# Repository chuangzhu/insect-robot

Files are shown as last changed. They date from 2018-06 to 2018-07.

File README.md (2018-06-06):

__中文 | [English](./README.en.md)__
# Insect Robot
用你的手机控制一只昆虫。  
>This project is greatly inspired by [Backyardbrains/Roboroach](https://github.com/backyardbrains/roboroach).  

insrobotop

insrobopack

## 开始
```Shell
git clone --recursive https://github.com/genelocated/insect-robot.git
```
#### 硬件
用 Eagle 7.7.0 打开 `hard/insect-robot.brd` 文件，选择 `文件 > CAM 处理器...` 。  
`文件 > 打开 > 作业...` , 打开 `gerb274x.cam` , 处理作业。  
打开作业 `excellon.cam` , 处理作业。  
将生成的 gerber 文件发给 pcb 打样厂。

#### 被控端固件

由于主控芯片采用的是 AVR，所以兼容 Arduino。可以使用 Arduino IDE 编程，具体请见 [arduino](./arduino/) 目录。

另一种方法：用 atmel studio 打开 `avr/controlled/insectRobot.atsln` , 运行 `build > build solution` 。  
生成的 hex 文件为 `Debug/controlled.hex` , 用 avrdude 或 progisp 烧录。需要用到 AVR asp。  
你还需要买一块 [FPC 6p 转接板](https://s.taobao.com/search?q=fpc+转接板+直插)。

#### 手机端
用微信扫描以下二维码打开小程序：  
QRcode

## 许可协议
本项目为开源硬件项目。

  
该项目本身采用[知识共享署名-相同方式共享 4.0 国际许可协议](https://creativecommons.org/licenses/by-sa/4.0/deed.zh)进行许可。  
小程序使用 MIT 协议进行许可。

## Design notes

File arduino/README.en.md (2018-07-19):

__English | [中文](./README.md)__

# Program using Arduino IDE

## Preparation

Locate at your Arduino config folder, it should one of the listed below:

```
\Arduino15\ (Windows, Arduino IDE 1.6.6 and newer)
\Arduino\ (Windows, Arduino IDE 1.0.6 and older)
\Documents\ArduinoData\ (Windows app version)
~/Library/Arduino15/ (Max OS X, Arduino IDE 1.6.0 and newer)
~/Library/Arduino/ (Max OS X, Arduino IDE 1.0.6 and older)
~/.arduino15/ (Linux, Arduino IDE 1.6.0 and newer)
~/.arduino/ (Linux, Arduino IDE 1.0.6 and older)
<Arduino IDE installation folder>/portable/ (when used in portable mode)
```

Open `packages/arduino/hardware/avr/1.6.21/boards.txt`, insert this content at the beginning of the file:

```makefile
insrobo.name=Insect Robot

insrobo.upload.tool=avrdude
insrobo.upload.protocol=arduino

insrobo.bootloader.tool=avrdude
insrobo.bootloader.unlock_bits=0x3F
insrobo.bootloader.lock_bits=0x0F

insrobo.build.board=AVR_PRO
insrobo.build.core=arduino
insrobo.build.variant=eightanaloginputs

insrobo.upload.maximum_size=30720
insrobo.upload.maximum_data_size=2048
insrobo.upload.speed=57600

insrobo.bootloader.low_fuses=0xE2
insrobo.bootloader.high_fuses=0xD9
insrobo.bootloader.extended_fuses=0xFF
insrobo.bootloader.file=atmega/ATmegaBOOT_168_atmega328.hex

insrobo.build.mcu=atmega328p
insrobo.build.f_cpu=8000000L
```

Besides, you may need a [USBtinyISP](https://www.amazon.com/s/field-keywords=USBtinyISP) to program.

## Let's start

Connect the board, the programmer and your computer in the way as is shown in the photo:

![connectprogrammer]()

Open Arduino IDE, select "Insect Robot" for board and "USBtinyISP" for programmer in "Tools" menu.

arduinotools

Then press "Upload Using Programmer" in the "Sketch" menu.

uploadwithprogrammer

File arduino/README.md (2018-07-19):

__中文 | [English](./README.en.md)__

# 使用 Arduino IDE 编程

## 准备工作

打开你的 Arduino 配置文件夹，它应该是以下其一：

```
\Arduino15\ (Windows, Arduino IDE 1.6.6 and newer)
\Arduino\ (Windows, Arduino IDE 1.0.6 and older)
\Documents\ArduinoData\ (Windows app version)
~/Library/Arduino15/ (Max OS X, Arduino IDE 1.6.0 and newer)
~/Library/Arduino/ (Max OS X, Arduino IDE 1.0.6 and older)
~/.arduino15/ (Linux, Arduino IDE 1.6.0 and newer)
~/.arduino/ (Linux, Arduino IDE 1.0.6 and older)
<Arduino IDE installation folder>/portable/ (when used in portable mode)
```

打开该目录下的 `packages\arduino\hardware\avr\1.6.21\boards.txt`，在文件开头粘贴以下内容：

```makefile
insrobo.name=Insect Robot

insrobo.upload.tool=avrdude
insrobo.upload.protocol=arduino

insrobo.bootloader.tool=avrdude
insrobo.bootloader.unlock_bits=0x3F
insrobo.bootloader.lock_bits=0x0F

insrobo.build.board=AVR_PRO
insrobo.build.core=arduino
insrobo.build.variant=eightanaloginputs

insrobo.upload.maximum_size=30720
insrobo.upload.maximum_data_size=2048
insrobo.upload.speed=57600

insrobo.bootloader.low_fuses=0xE2
insrobo.bootloader.high_fuses=0xD9
insrobo.bootloader.extended_fuses=0xFF
insrobo.bootloader.file=atmega/ATmegaBOOT_168_atmega328.hex

insrobo.build.mcu=atmega328p
insrobo.build.f_cpu=8000000L
```

此外，你还需要购买一个 [USBtinyISP](https://s.taobao.com/search?q=USBtinyISP)。

## 开始编程

如图所示连接电路板、编程器和电脑：

![connectprogrammer]()

打开 Arduino IDE，在工具中将开发板设置为 Insect Robot、编程器设置为 USBtinyISP。

arduinotools

点击项目菜单中的”使用编程器上传“即可。

uploadwithprogrammer

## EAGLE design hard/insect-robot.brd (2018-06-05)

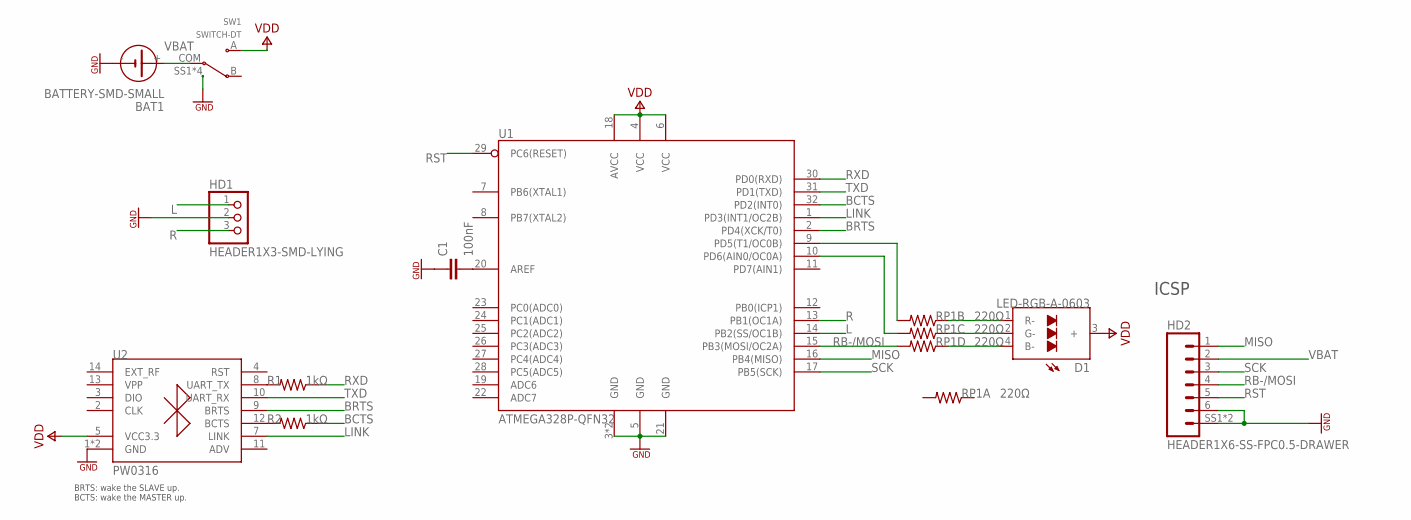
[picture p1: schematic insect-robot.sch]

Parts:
BAT1: BATTERY-SMD-SMALL; BAT-SMD-SMALL
C1: 100nF; SMD0603
D1: LED-RGB-A-0603; LED-0603X2
HD1: HEADER1X3-SMD-LYING; SMD-1X3-LYING
HD2: HEADER1X6-SS-FPC0.5-DRAWER; FPC0.5-6-DRAWER
R1, R2: 1kΩ; SMD0603
RP1: 220Ω; RP0603
SW1: SWITCH-DT; SWITCH-SMD-6.7X2.7
U1: ATMEGA328P-QFN32; QFN32
U2: PW0316

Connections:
AREF: C1.2, U1.20 (AREF)
B-: D1.4 (B-), RP1.7 (1)
BCTS: R2.1, U1.32 (PD2(INT0))
BRTS: U1.2 (PD4(XCK/T0)), U2.9 (BRTS)
G-: D1.2 (G-), RP1.5 (1)
GND: BAT1.-, C1.1, HD1.2, HD2.6, HD2.SS1 (7), HD2.SS2 (7), SW1.SS1 (SS), SW1.SS2 (SS), SW1.SS3 (SS), SW1.SS4 (SS), U1.3 (GND), U1.5 (GND), U1.21 (GND), U1.EP (GND), U2.1 (GND), U2.6 (GND)
L: HD1.1, U1.14 (PB2(SS/OC1B))
LINK: U1.1 (PD3(INT1/OC2B)), U2.7 (LINK)
MISO: HD2.1, U1.16 (PB4(MISO))
R: HD1.3, U1.13 (PB1(OC1A))
R-: D1.1 (R-), RP1.3 (1)
R-BCTS: R2.2, U2.12 (BCTS)
R-TX: R1.2, U2.8 (UART_TX)
RB-/MOSI: HD2.4, RP1.8 (2), U1.15 (PB3(MOSI/OC2A))
RG-: RP1.6 (2), U1.10 (PD6(AIN0/OC0A))
RR-: RP1.4 (2), U1.9 (PD5(T1/OC0B))
RST: HD2.5, U1.29 (PC6(RESET))
RXD: R1.1, U1.30 (PD0(RXD))
SCK: HD2.3, U1.17 (PB5(SCK))
TXD: U1.31 (PD1(TXD)), U2.10 (UART_RX)
VBAT: BAT1.+, HD2.2, SW1.COM
VDD: D1.3 (+), SW1.A, U1.4 (VCC), U1.6 (VCC), U1.18 (AVCC), U2.5 (VCC3.3)

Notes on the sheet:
ICSP
BRTS: wake the SLAVE up. BCTS: wake the MASTER up.

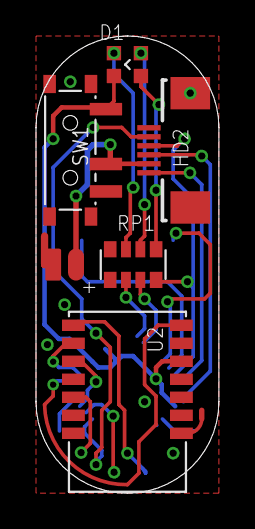
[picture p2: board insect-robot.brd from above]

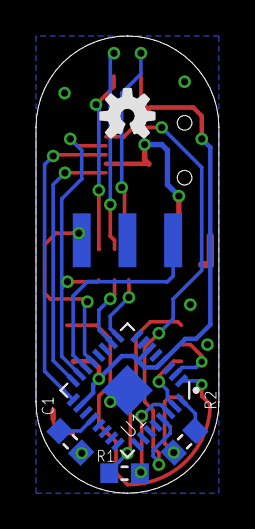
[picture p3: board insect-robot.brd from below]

Board: 2 copper layers, 10.2 x 25.4 mm, 12 parts (6 on the bottom side), 22 nets.

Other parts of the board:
OSHW: ICON-OSHW

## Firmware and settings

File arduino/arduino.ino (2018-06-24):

/* Don't save this file as "UTF-8 with BOM" */

// color ranges from 0x00 to 0xFF,
// we use an array of char to store r, g, b
// in this case we can send it via BLE boardcast
char ledColor[3];

void randColor() {
  for (int i = 0; i<3; i++) {
    // use the values read from unconnected analog pins as random seed
    randomSeed(analogRead(3) + analogRead(6));
    ledColor[i] = random(256);
  }
}

// LED pins
const int RED = 5;
const int GREEN = 6;
const int BLUE = 11;
// electrode pins
const int LEFT = 10;
const int RIGHT = 9;

void setup() {
  pinMode(RED, OUTPUT);
  pinMode(GREEN, OUTPUT);
  pinMode(BLUE, OUTPUT);
  // a pin is in Hi-Z state when it is INPUT and LOW.
  // we only make these pins OUTPUT when we need to make them HIGH.
  // this measure prevented the possibility of
  // letting the current flows from one antenna to another.
  pinMode(LEFT, INPUT);
  pinMode(RIGHT, INPUT);
  randColor(); // get a random color
  // show this random color on the LED
  analogWrite(RED, 255 - ledColor[0]);
  analogWrite(GREEN, 255 - ledColor[1]);
  analogWrite(BLUE, 255 - ledColor[2]);
  Serial.begin(9600);
  delay(128);
  // rename the bluetooth low energy (BLE) module to '$sect'
  Serial.println("TTM:REN-$sect");
  // leave time for the module to deal with the task
  delay(128);
  // share the random color via BLE boardcast 
  Serial.print("TTM:ADD-");
  Serial.print(ledColor);
  delay(255);
}



// parameters for the impulse wave
const int impulsePeriod = 30; // *10us
const int impulseDuty = 20; // *10us
const int impulseTimeout = 1000; // *10us

boolean impulse = false;
int impulsePin;
int loopStep = 0;
int impulseTimes = 0;

//   impulsePeriod
//  |<----------->|
//   __________    __________      HIGH
//             |  |          |
//             |__|          |__   LOW
//
//  |<-------->|             |<>|
//   impulseDuty        (impulsePriod - impulseDuty)
//
//           |   zoom out
//           V
//        _   _   _   _   _   _   _
//  ------ |_| |_| |_| |_| |_| |_| |_------
//       |<------------------------->|
//              impulseTimeout

void loop() {
  if (impulse) {
    if (loopStep == impulseDuty) {
      digitalWrite(impulsePin, LOW);
    } else if (loopStep == impulsePeriod) {
      loopStep = 0;
      digitalWrite(impulsePin, HIGH); 
    }
    loopStep ++;
    if (impulseTimes == impulseTimeout) {
      impulseTimes = 0;
      pinMode(impulsePin, INPUT);
      digitalWrite(impulsePin, LOW);
      impulse = false;
    }
    impulseTimes ++;
    delayMicroseconds(10);
  }
}



String inString = "";

void serialEvent() {
  while (Serial.available()) {
    char inChar = Serial.read();
    inString += inChar; // append to the string
    if (inString == "EL:LLL") {
      inString = "";
      impulsePin = LEFT;
      pinMode(impulsePin, OUTPUT);
      impulse = true; // start impulse wave
    } else if (inString == "EL:RRR") {
      inString = "";
      impulsePin = RIGHT;
      pinMode(impulsePin, OUTPUT);
      impulse = true;
    }
  }
}

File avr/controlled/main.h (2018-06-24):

/*
 * main.h
 *
 * Created: 2018/4/28 22:28:03
 *  Author: geneLocated
 */ 


#ifndef MAIN_H_
#define MAIN_H_

#include <avr/io.h>
#include <avr/interrupt.h>
#include <util/delay.h>
#include <stdlib.h>
#include <string.h>
#include "../lib/USART/HAL_USART.h"
#include "../lib/ADC/HAL_ADC.h"

//Pins definitions.
#define RXD		PORTD0
#define TXD		PORTD1
#define BCTS	PORTD2
#define LINK	PORTD3
#define BRTS	PORTD4

#define eleLeft		PORTB2
#define eleRight	PORTB1

//This commit corrected LED to PWM pins,
#define ledR PORTD5	//OC0B
#define ledG PORTD6	//OC0A
#define ledB PORTB3	//OC2A

#define PWM_0B_ENABLE
#define PWM_0A_ENABLE
#define PWM_2A_ENABLE
#include "../lib/PWM/HAL_PWM.h"

#define set(Reg, Bit)	Reg |= (1<<Bit)		//Set a bit of reg.
#define clr(Reg, Bit)	Reg &= ~(1<<Bit)	//Clear a bit of reg.
#define not(Reg, Bit)	Reg ^= (1<<Bit)		//Reverse a bit of reg.

unsigned char ledDuty[3];

#define elePeriod	30		//*10us
#define eleDuty		20		//*10us
#define eleTimeout	1000	//*10us

unsigned char pwmElePin;

#endif /* MAIN_H_ */

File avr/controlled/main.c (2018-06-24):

/*
 * controlled.c
 *
 * Created: 2018/4/28 20:59:13
 * Author : geneLocated
 */ 

#include "main.h"

unsigned char ledDuty[3] = {0};
unsigned char impulse = 0;

/** Give random color using a hanging ADC port as random seed */
#define randColor(yourColor) {\
	ADC_Init();\
	for (unsigned char i = 0; i<3; i++) {\
		srand(ADConvert(3) + ADConvert(6));\
		yourColor[i] = rand() % 256;\
	}\
	ADC_Disable();\
}

#define setLEDDuty() {\
	PWM_0B(255 - ledDuty[0]);\
	PWM_0A(255 - ledDuty[1]);\
	PWM_2A(255 - ledDuty[2]);\
}

int main(void)
{
	DDRD = (1<<TXD)|(1<<BRTS);
	DDRB = (1<<ledR)|(1<<ledG)|(ledB<<1);
	//Hi-Z state if both DDRCn & PORTCn is 0
	DDRC = 0x00 /* (1<<eleLeft)|(1<<eleRight) */;
	randColor(ledDuty);
	USART_Begin();
	_delay_ms(128);
	USART_SendData("TTM:REN-$sect\r\n", 17);
	_delay_ms(128);
	USART_SendData("TTM:ADD-", 8);
	USART_SendData((char*)ledDuty, 3);
	_delay_ms(255);
	PWM_Init();
	setLEDDuty();
	sei();
	
	//    elePeriod
	//  |<----------->|
	//   __________    __________      HIGH
	//             |  |          |
	//             |__|          |__   LOW
	//
	//  |<-------->|             |<>|
	//    eleDuty          (elePriod - eleDuty)
	//
	//           |   zoom out
	//           V
	//        _   _   _   _   _   _   _
	//  ------ |_| |_| |_| |_| |_| |_| |_------
	//       |<------------------------->|
	//                eleTimeout
	
	while (1)
	{
		if (impulse)
		{
			static unsigned char loopStep = 0;
			static unsigned int eleTime = 0;
			if (loopStep == eleDuty)
				clr(PORTB, pwmElePin);
			else if (loopStep >= elePeriod)
			{
				loopStep = 0;
				set(PORTB, pwmElePin);
			}
			loopStep ++;
			if (eleTime >= eleTimeout)
			{
				eleTime = 0;
				clr(DDRB, pwmElePin);
				clr(PORTB, pwmElePin);
				impulse = 0;	// FALSE
			}
			eleTime ++;
			_delay_us(10);
		}
	}
}

char usartBuf[4] = {0, 0, 0, 0};
unsigned char modeFlag = 0;
#define noMode		(0)
#define eleMode		(1)

ISR(USART_RX_vect)
{
	static unsigned char usartIndex = 0;
	usartBuf[usartIndex] = UDR0;
	if (usartIndex == 2)
	{
		if (modeFlag == noMode)
		{
			if (!strcmp(usartBuf, "EL:"))
				modeFlag = eleMode;
		}
		else if (modeFlag == eleMode)
		{
			modeFlag = noMode;
			if (!strcmp(usartBuf, "LLL"))
				pwmElePin = eleLeft;
			else if (!strcmp(usartBuf, "RRR"))
				pwmElePin = eleRight;
			set(DDRB, pwmElePin);
			impulse = 1;	//TRUE
		}
	}
	usartIndex ++;
	if (usartIndex > 2)
		usartIndex = 0;
}

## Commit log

2018-03-03 Add MCU and battery
    [insect-robot.sch]
2018-03-03 Add bluetooth module
    [insect-robot.sch]
2018-03-31 Add MOSFET for charging control
    [insect-robot.sch]
2018-03-31 Add ISP programming port
    [insect-robot.sch]
2018-03-31 Add RGB LED
    [insect-robot.sch]
2018-03-31 Connect pins
    [insect-robot.sch]
2018-03-31 Create board
    [insect-robot.brd]
2018-04-01 Place the components
    [insect-robot.brd, insect-robot.sch]
2018-04-01 Place components
    [insect-robot.brd, insect-robot.sch]
2018-04-01 Redraw some components
    [insect-robot.brd, insect-robot.sch]
2018-04-01 Route some wires
    [insect-robot.brd, insect-robot.sch]
2018-04-01 Done routing
    [insect-robot.brd, insect-robot.sch]
2018-04-01 Place labels
    [insect-robot.brd, insect-robot.sch]
2018-04-05 Relocate some components
    [insect-robot.brd]
2018-04-14 Redesign finished
    [insect-robot.brd, insect-robot.sch]
2018-04-21 Fixed RGB LED footprint
    [insect-robot.brd, insect-robot.sch]
2018-04-22 Add devices page, bluetooth
2018-04-30 Using BLE module, I can control LED now
2018-05-01 Add LED PWM
2018-05-01 Simple implementation of electrode
2018-05-07 Device color sharing
2018-05-12 Add new mode to fix ble devices refresh
2018-05-19 Electrode pwm
2018-06-03 PWM pins
    [insect-robot.brd, insect-robot.sch]
2018-06-03 Remove non-PWM elctrode pins
    [insect-robot.brd, insect-robot.sch]
2018-06-03 LED __hardware__ PWM
    [insect-robot.brd]
2018-06-05 Fix TIMER1
2018-06-05 Arduino init
2018-06-06 Add arduino chinese readme
2018-06-06 Add arduino english readme
2018-06-06 Which write button
2018-06-06 Update README for arduino
2018-06-18 Fix electrode pins
2018-06-18 Fix common anode led in SCH
    [insect-robot.sch]
2018-06-23 Fix color reversing display
    [arduino.ino, main.c]
2018-06-24 Cancel using TIMER1
2018-06-30 Arduino readme USBtinyISP
2018-06-30 Add adapter scheme
    [adaptor.sch]
2018-06-30 Add ISP adaptor board
    [adaptor.brd, adaptor.sch]
2018-07-25 Show other devices
2018-07-29 Optimise using button type
2018-07-30 Add devices multilang

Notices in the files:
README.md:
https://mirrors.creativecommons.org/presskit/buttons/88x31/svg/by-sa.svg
